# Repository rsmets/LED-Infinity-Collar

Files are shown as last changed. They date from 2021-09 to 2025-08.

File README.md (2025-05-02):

# LED Infinity Mirror Collar

This repo houses the materials in order to construct a LED infinity mirror collar. The original inspiration for this project I can not take credit for. Adafruit released a [guide](https://learn.adafruit.com/infinity-mirror-collar) that I originally followed. However since there has been slightly modifications to the physical construction and the software as well.

## Firmware

### How to Flash Bootloader

#### OpenOCD

Need to use the serial interface.

1. Open serial connection using openocd

```sh
openocd -f interface/stlink.cfg -f target/nrf52.cfg
```

1. In a separate terminal, open the arm gdb

```sh
arm-none-eabi-gdb
```

2. Connect to target

```sh
target remote localhost:3333
```

3. Download the [itsybitsy hex firmware](https://github.com/adafruit/Adafruit_nRF52_Bootloader/releases) or use the file in the ./Bootloader directory.

4. Load the firmware

```sh
load /Users/raysmets/dev/LED-Infinity-Collar/Bootloader/itsybitsy_nrf52840_express_bootloader-0.8.3_s140_6.1.1.hex

```

4. Reset the monitor and continue

```sh
monitor reset
continue
```

#### J-Link

You'll if the nRF52 has APProtect (Access Port Protection) enabled (via UICR settings), you must use a J-Link to “recover” it.

1. Connect

```sh
JLinkExe -if SWD -device NRF52840_XXAA -speed 4000
```

2. Connect

```sh
connect
```

3. Erase

```sh
erase
```

4. Load the firmware

```sh
loadfile /Users/raysmets/dev/LED-Infinity-Collar/Bootloader/itsybitsy_nrf52840_express_bootloader-0.8.3_s140_6.1.1.hex
```

### Install Circuit Python

Now that you have the itsybitys bootloader installed you can flash the it with CircuitPython. You should be able to see the microcontroller over the the usb interface now.

1. [Download](https://adafruit-circuit-python.s3.amazonaws.com/index.html?prefix=bin/itsybitsy_nrf52840_express/en_US/) the target U2F [Circuit Python](https://circuitpython.org/board/itsybitsy_nrf52840_express/) file or can use the files already in ./Bootloader directory.

2. [Install Circuit Python](https://learn.adafruit.com/welcome-to-circuitpython/installing-circuitpython) by copying [ItsyBitsy](https://learn.adafruit.com/adafruit-itsybitsy-nrf52840-express/circuitpython) uf2 file to main drive. It should then show up in volumes as circuit python!

```sh
cp Bootloader/adafruit-circuitpython-itsybitsy_nrf52840_express-en_US-8.2.9.uf2 /Volumes/ITSY840BOOT
```

### Upgrading the Bootloader

To [update the bootloader](https://learn.adafruit.com/introducing-the-adafruit-nrf52840-feather/update-bootloader-use-command-line#) you could use the method described above or you could use the usb serial interface and the Adafruit nrfutil. Full directions to do so here.

1. Download [./adafruit-nrfutil](https://learn.adafruit.com/introducing-the-adafruit-nrf52840-feather/update-bootloader-use-command-line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) bin
2. Find the serial interface device name

```sh
ls /dev/cu.*
```

3. Download the [zip bootloader file](https://github.com/adafruit/Adafruit_nRF52_Bootloader/releases)

4. [Update the bootloader](https://learn.adafruit.com/introducing-the-adafruit-nrf52840-feather/update-bootloader-use-command-line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) with the command below with the target bootload zip file you want and the serial name.

```sh
./adafruit-nrfutil --verbose dfu serial --package itsybitsy_nrf52840_express_bootloader-0.9.2_s140_6.1.1.zip -p /dev/cu.usbmodem101 -b 115200 --singlebank --touch 1200
```

## Software

### Circuit Python

The ItsyBitsy_Infinity_Collar directory contains the Circuit Python code necessary to drive the animations. It also contains the necessary Adafruit libraries to work appropriately. I opted to go with more stable CircuitPython 6.x firmware and in that folder you will find the modified `code.py` which can be directory cp'd to the root of the ItsyBitsy microcontroller.

### Personal Software Modifications

Currently the extend of the software modifications entail variable brightness control via the BLE interface via the BlueFruit mobile application. Upon connecting navigate to the control pad menu and use the `up` and `down` arrows to control the LED brightness.

## Physical Housing

### 3D

The 3D directory contains files from which I took the provided SVGs for the collar's physical construction and turned them into STL files to be 3D printed.

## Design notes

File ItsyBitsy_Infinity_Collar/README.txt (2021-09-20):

This bundle contains two folders, one each for CircuitPython 6.x and CircuitPython 7.x. You must use the files that match the version of CircuitPython you're using, e.g. if you are using CircuitPython 6, you will copy the files from the CircuitPython 6.x folder to your CIRCUITPY drive.

To use this project bundle, simply copy the contents of the CircuitPython version folder you're using from the zip file to your CIRCUITPY drive.
Contents in each version include:
* the code.py file
* the lib/ folder and all of its contents (including subfolders and .mpy or .py files)
* any assets (such as images, sounds, etc.)

NOTE: This will replace the current code.py, and the lib folder and its contents. Back up any desired code before copying these files!

 This zip was downloaded from https://learn.adafruit.com/infinity-mirror-collar/glow-baby-glow on September 19, 2021.

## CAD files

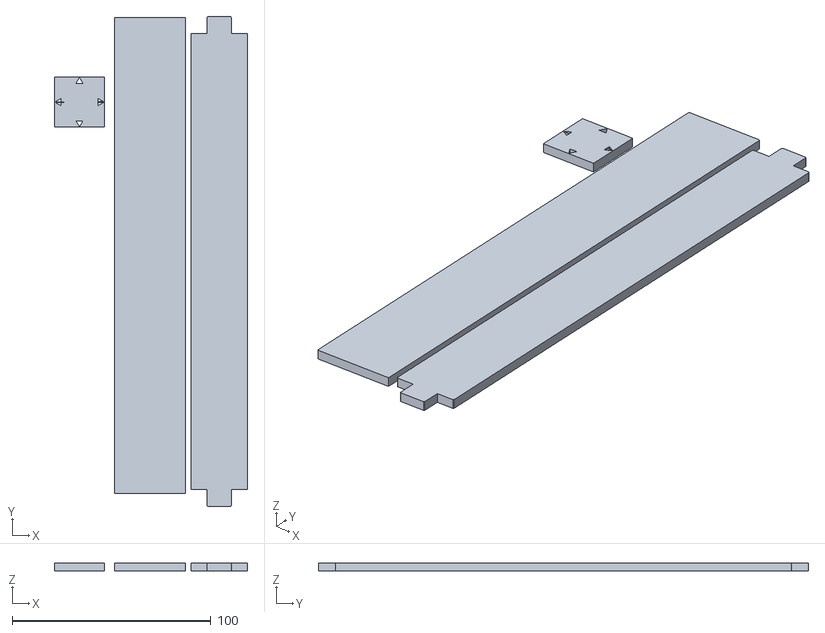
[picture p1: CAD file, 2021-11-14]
3D/Holographic_4h.stl
97.3 x 246.7 x 4.00

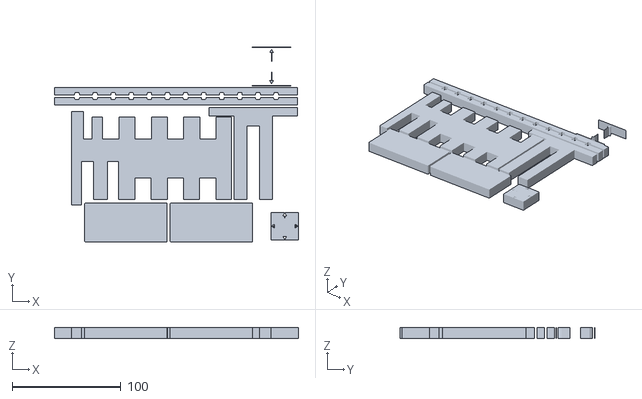
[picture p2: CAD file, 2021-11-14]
3D/EVAFoam_10h.stl
224.7 x 179.4 x 10.0

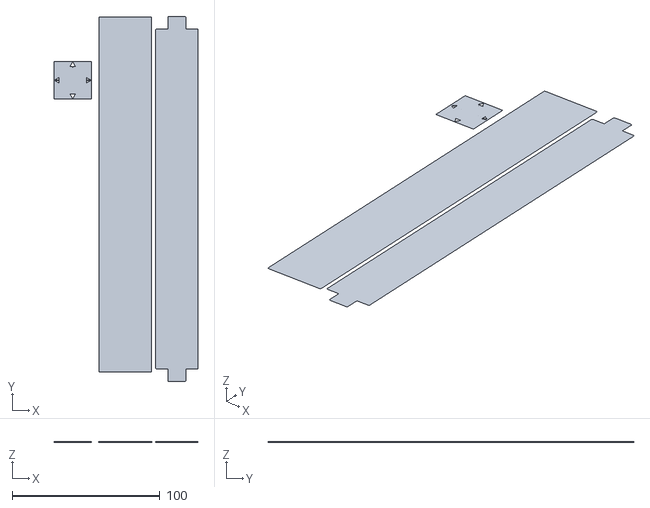
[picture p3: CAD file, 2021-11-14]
3D/Holographic_1h.stl
97.3 x 246.7 x 0.1

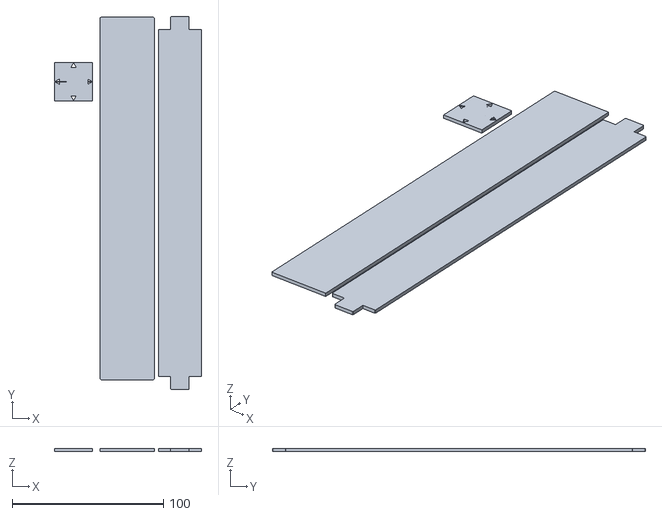
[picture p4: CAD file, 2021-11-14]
3D/Holographic_2h.stl
97.3 x 246.7 x 2.00

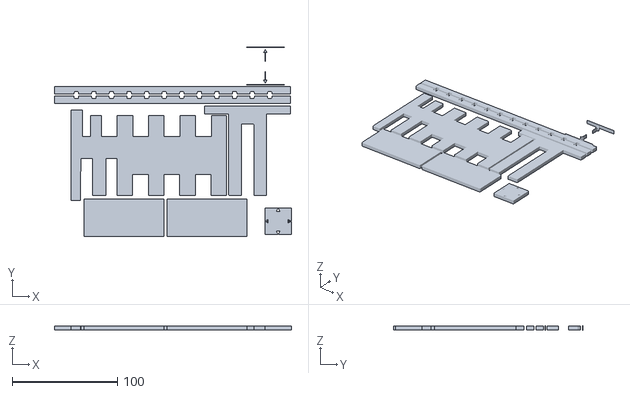
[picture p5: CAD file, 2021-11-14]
3D/EVAFoam_4h.stl
224.7 x 179.4 x 4.00

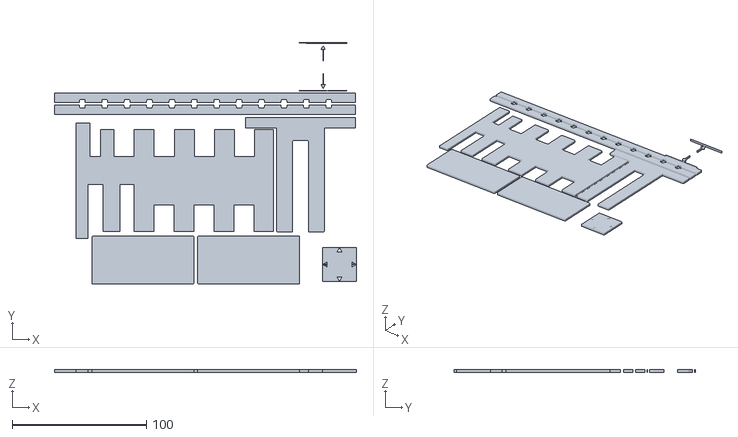
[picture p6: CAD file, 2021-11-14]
3D/EVAFoam_2h.stl
224.7 x 179.4 x 2.00

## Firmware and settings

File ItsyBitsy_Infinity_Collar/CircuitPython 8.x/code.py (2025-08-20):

"""
Code for the LED Infinity Mirror Collar. Allows the animation sequence
and color to be controlled by input from the Adafruit Bluefruit App
"""

import random

import board
import digitalio
import neopixel

# Bluetooth modules
from adafruit_ble import BLERadio
from adafruit_ble.advertising.standard import ProvideServicesAdvertisement
from adafruit_ble.services.nordic import UARTService
from adafruit_bluefruit_connect.button_packet import ButtonPacket
from adafruit_bluefruit_connect.color_packet import ColorPacket
from adafruit_bluefruit_connect.packet import Packet
from adafruit_debouncer import Debouncer
from adafruit_led_animation.animation.chase import Chase

# LED Animation modules
from adafruit_led_animation.animation.comet import Comet
from adafruit_led_animation.animation.pulse import Pulse
from adafruit_led_animation.animation.rainbowcomet import RainbowComet
from adafruit_led_animation.color import colorwheel
from adafruit_led_animation.sequence import AnimationSequence

# NeoPixel control pin
pixel_pin = board.D5

# Number of pixels in the collar (arranged in two rows)
pixel_num = 30
# pixel_num = 22 # for the original collar

pixels = neopixel.NeoPixel(pixel_pin, pixel_num, brightness=0.05, auto_write=False)

# Create a switch from the ItsyBity's on-board pushbutton to toggle charge mode
mode_pin = digitalio.DigitalInOut(board.SWITCH)
mode_pin.direction = digitalio.Direction.INPUT
mode_pin.pull = digitalio.Pull.UP
switch = Debouncer(mode_pin)

# Create the animations - will use dynamic proportional brightness
# Initial colors will be overridden by random_animation_color function
comet = Comet(
    pixels, speed=0.1, color=(255, 255, 255), tail_length=10, bounce=True
)
chase = Chase(
    pixels,
    speed=0.12,
    size=3,
    spacing=5,
    color=(255, 255, 255),
    reverse=True,
)
rainbow_comet = RainbowComet(pixels, speed=0.08)
pulse = Pulse(
    pixels, speed=0.08, color=(255, 255, 255), period=2.5
)

# Set initial proportional colors
initial_color = (80, 0, 40)  # Deep red base color
comet.color = initial_color  # 1 LED = full brightness
chase.color = tuple(int(c / 3) for c in initial_color)  # 3 LEDs = 1/3 brightness
pulse.color = tuple(int(c / 30) for c in initial_color)  # 30 LEDs = 1/30 brightness


# Our animations sequence
seconds_per_animation = 10
animations = AnimationSequence(
    comet,
    rainbow_comet,
    chase,
    pulse,
    advance_interval=seconds_per_animation,
    auto_clear=True,
    auto_reset=True,
)
# animations = AnimationSequence(
#    comet, rainbow_comet, advance_interval=seconds_per_animation, auto_clear=True
# )
# animations = AnimationSequence(pulse, auto_clear=True)
# Current display determines whether we are showing the animation sequence or the pulse animation
current_display = animations

# Mode changes the color of random animations randomly
random_color_mode = True


def random_animation_color(anims):
    if random_color_mode:
        # Pick a new random color but keep it subdued (max 80 brightness)
        full_color = colorwheel(random.randint(0, 255))
        # Scale down to subdued brightness (max 80 instead of 255)
        base_color = tuple(int(c * 80 / 255) for c in full_color)

        # Apply proportional brightness scaling
        # Comet: 1 LED = full subdued brightness
        comet.color = base_color

        # Chase: 3 LEDs = 1/3 brightness
        chase.color = tuple(int(c / 3) for c in base_color)

        # Pulse: 30 LEDs = 1/30 brightness
        pulse.color = tuple(int(c / 30) for c in base_color)

        # Set sequence color to base color
        anims.color = base_color


# Add receiver only for animation sequence changes (not individual animation cycles)
animations.add_cycle_complete_receiver(random_animation_color)


# Initialize with a random subdued color if enabled so we don't start on the hardcoded initial color
random_animation_color(animations)

# After we complete three pulse cycles, return to main animations list
def pulse_finished(anim):
    global current_display
    current_display = animations


pulse.add_cycle_complete_receiver(pulse_finished)
pulse.notify_cycles = 3


# Bluetooth
ble = BLERadio()
ble.name = "LED Infinity Collar v2.a"  # Set a custom name for the BLE device
uart_service = UARTService()
advertisement = ProvideServicesAdvertisement(uart_service)

# Set charge_mode to True to turn off the LED Animations and Bluetooth
#  e.g. when charging the battery
charge_mode = False

ble_connected_message = False


# Checks the ItsyBitsy's switch button
def check_switch():
    global charge_mode
    switch.update()
    if switch.fell:  # Switch changed state
        charge_mode = not charge_mode
        # if display has just been turned off, clear all LEDs, disconnect, stop advertising
        if charge_mode:
            print("charge mode")
            pixels.fill((0, 0, 0))
            pixels.show()
            if ble.connected:
                for conn in ble.connections:
                    conn.disconnect()
            if ble.advertising:
                ble.stop_advertising()


# Main program loop
while True:
    # Check whether charge mode has been changed
    check_switch()
    if charge_mode:
        pass
    else:
        current_display.animate()
        if ble.connected:
            if not ble_connected_message:
                print("ble connected")
                ble_connected_message = True
            if uart_service.in_waiting:
                # Packet is arriving
                packet = Packet.from_stream(uart_service)
                if isinstance(packet, ButtonPacket) and packet.pressed:
                    if packet.button == ButtonPacket.BUTTON_1:
                        # Animation colors change to a random new value after every animation sequence
                        random_color_mode = True
                        print(
                            "button 1 pressed: Animation colors change to a random new value after every animation sequence"
                        )
                    elif packet.button == ButtonPacket.BUTTON_2:
                        # Animation colors stay the same unless manually changed
                        random_color_mode = False
                        print(
                            "button 2 pressed: Animation colors stay the same unless manually changed"
                        )
                    elif packet.button == ButtonPacket.BUTTON_3:
                        # Stay on the same animation
                        animations._advance_interval = None
                        print("button 3 pressed: Stay on the same animation")
                    elif packet.button == ButtonPacket.BUTTON_4:
                        # Auto-advance animations
                        # Library stores _advance_interval in milliseconds
                        animations._advance_interval = seconds_per_animation * 1000
                        print("button 4 pressed: Auto-advance animations")
                    elif packet.button == ButtonPacket.LEFT:
                        # Go to first animation in the sequence
                        animations.activate(0)
                        print(
                            "button left pressed: Go to first animation in the sequence"
                        )
                    elif packet.button == ButtonPacket.RIGHT:
                        # Go to the next animation in the sequence
                        animations.next()
                        print(
                            "button right pressed: Go to next animation in the sequence"
                        )
                    elif packet.button == ButtonPacket.UP:
                        # Increase brightness
                        # Clamp to a safe subdued range to avoid wrap-around and overly bright output
                        pixels.brightness = min(0.2, round(pixels.brightness + 0.025, 3))
                        print("button up pressed: Increase brightness ")
                        print(pixels.brightness)
                    elif packet.button == ButtonPacket.DOWN:
                        # Decrease brightness
                        pixels.brightness = max(0.02, round(pixels.brightness - 0.025, 3))
                        print("button down pressed: Decrease brightness ")
                        print(pixels.brightness)
                elif isinstance(packet, ColorPacket):
                    # Update all animations with proportional brightness
                    # Scale down BLE color to subdued brightness (max 80 instead of 255)
                    full_color = packet.color
                    base_color = tuple(int(c * 80 / 255) for c in full_color)

                    # Apply proportional brightness scaling
                    comet.color = base_color  # 1 LED = full subdued brightness
                    chase.color = tuple(
                        int(c / 3) for c in base_color
                    )  # 3 LEDs = 1/3 brightness
                    pulse.color = tuple(
                        int(c / 30) for c in base_color
                    )  # 30 LEDs = 1/30 brightness
                    animations.color = base_color
                    # temporarily change to pulse display to show off the new color
                    print(
                        "color picker used: temporarily change to pulse display to show off the new color"
                    )
                    current_display = pulse

        else:
            # print("ble...")
            if not ble.advertising:
                print("ble not advertising... starting to")
                ble.start_advertising(advertisement)

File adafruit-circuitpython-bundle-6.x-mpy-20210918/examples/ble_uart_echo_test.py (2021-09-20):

# SPDX-FileCopyrightText: 2020 ladyada for Adafruit Industries
# SPDX-License-Identifier: MIT

"""
Can be used with ble_uart_echo_client.py or with the UART page on the Adafruit Bluefruit Connect app.
Receives characters from the UARTService and transmits them back.
"""

from adafruit_ble import BLERadio
from adafruit_ble.advertising.standard import ProvideServicesAdvertisement
from adafruit_ble.services.nordic import UARTService

ble = BLERadio()
uart = UARTService()
advertisement = ProvideServicesAdvertisement(uart)

while True:
    ble.start_advertising(advertisement)
    while not ble.connected:
        pass
    while ble.connected:
        # Returns b'' if nothing was read.
        one_byte = uart.read(1)
        if one_byte:
            print(one_byte)
            uart.write(one_byte)

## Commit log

2021-11-14 [3D] stls, gcdoe, and original svg fro the physical collar contstruction added.
    [EVAFoam_10h.stl, EVAFoam_2h.stl, EVAFoam_4h.stl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]
2025-05-02 [CircuitPython] v8 and latest u2f hex bootloader. Also README updated (#1)
    * readme
    * wip
    * README
2025-05-03 [CircuityPython] v8 libs and code
2025-08-20 [Brightness] updated and pulse and chase animation added back in mix. (#2)
    * [Animations] in v8 code slightly modified for taste
    * [Brightness]
    * [Animations] finish before switching
    * [Colors] changing on each animation
    * [Colors]
    * [Brightness] limitted by led count of animation
    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
